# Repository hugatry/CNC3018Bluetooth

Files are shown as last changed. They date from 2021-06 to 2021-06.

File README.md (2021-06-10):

# CNC3018Bluetooth
 HM-10 based bluetooth module for CNC 3018 (Pro). Works with Woodpecker 3.4 and other compatible CNC controller boards.
 
 [Video introducing/testing this project](https://youtu.be/gbWO2Mq1XHM)

## HM-10 configuration
 This add-on module is ment to be used with HM-10 based USB dongle.
 Starting from HM-10 default configuration, CNC add-on module works as is, but USB-dongle needs to be set as Central/Master with "AT+ROLE1".
 
 It's recommended to use firmware version V700 or newer, which has correct baud rate and possibly other configurations as default. Hm-10 modules with older firmware may or may not work.
 
 ## Changes after the video, before the initial commit:
 * Ground pour removed behind the antenna
 * HM-10 ground pads are actually connected to the circuit :)

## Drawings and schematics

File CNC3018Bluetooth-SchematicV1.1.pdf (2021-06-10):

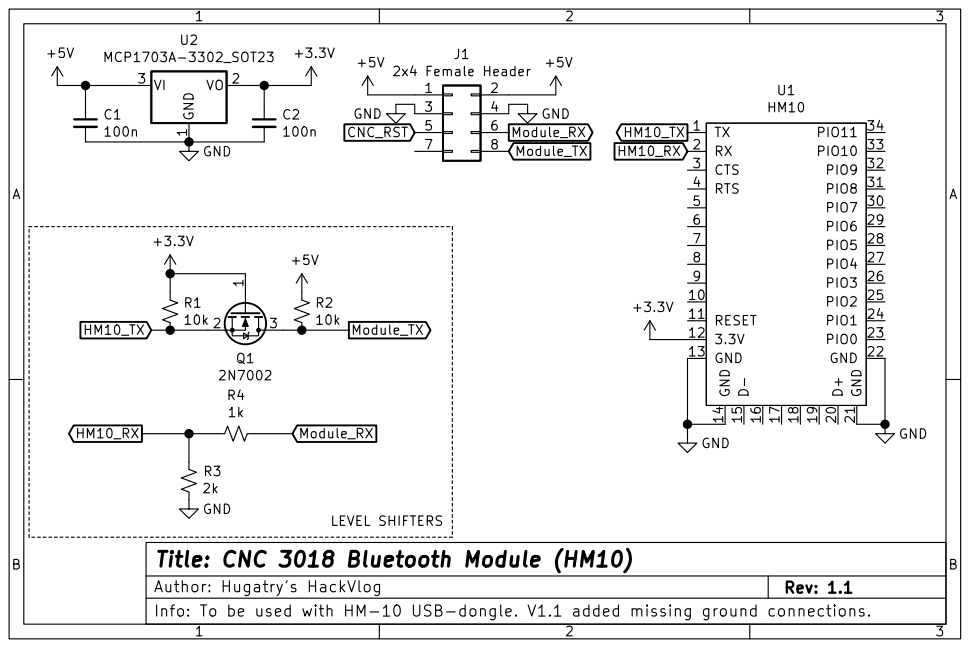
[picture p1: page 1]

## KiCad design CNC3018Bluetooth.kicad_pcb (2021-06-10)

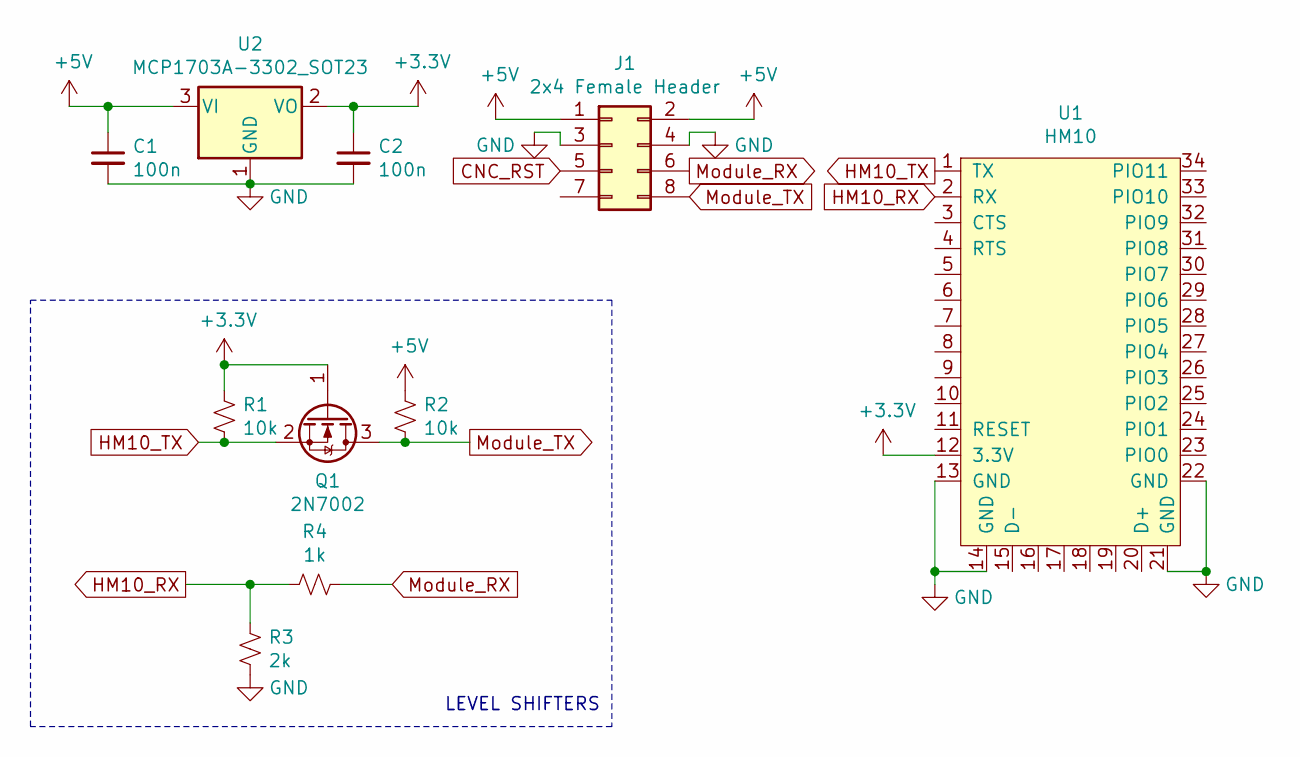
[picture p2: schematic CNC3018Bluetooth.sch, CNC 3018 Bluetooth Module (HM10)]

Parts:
C1, C2: 100n; C_0603_1608Metric
J1: 2x4 Female Header; PinSocket_2x04_P2.54mm_Vertical
Q1: 2N7002; SOT-23
R1, R2: 10k; R_0603_1608Metric
R3: 2k; R_0603_1608Metric
R4: 1k; R_0603_1608Metric
U1: HM10
U2: MCP1703A-3302_SOT23; SOT-23

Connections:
+3V3: C2.1, Q1.1 (G), R1.1, U1.12 (3.3V), U2.2 (VO)
+5V: C1.1, J1.1, J1.2, R2.1, U2.3 (VI)
CNC_RST: J1.5
GND: C1.2, C2.2, J1.3, J1.4, R3.1, U1.13 (GND), U1.14 (GND), U1.21 (GND), U1.22 (GND), U2.1 (GND)
HM10_RX: R3.2, R4.2, U1.2 (RX)
HM10_TX: Q1.2 (S), R1.2, U1.1 (TX)
Module_RX: J1.6, R4.1
Module_TX: J1.8, Q1.3 (D), R2.2

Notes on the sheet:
LEVEL SHIFTERS

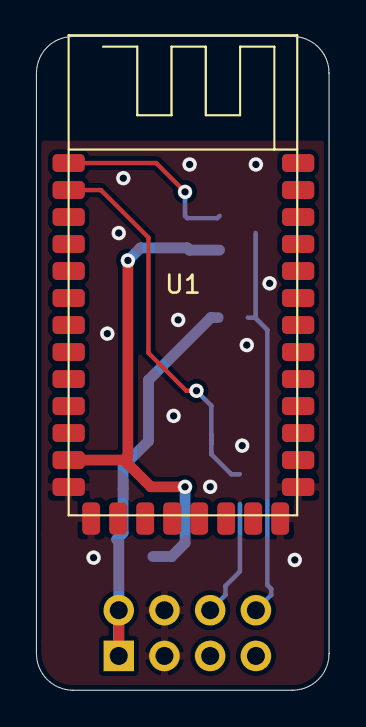
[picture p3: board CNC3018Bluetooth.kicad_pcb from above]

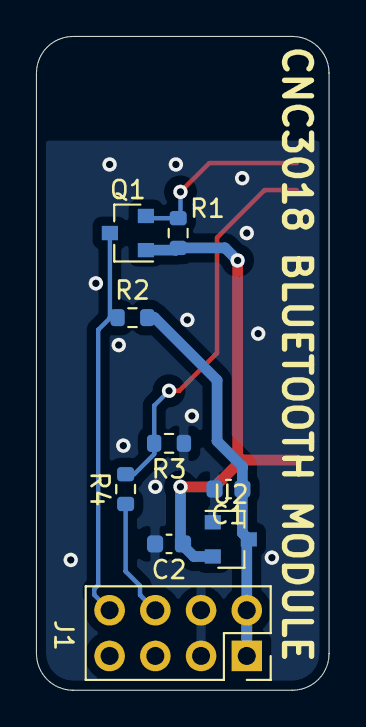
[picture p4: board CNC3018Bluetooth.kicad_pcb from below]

Board: 2 copper layers, 16.3 x 36.3 mm, 10 parts (9 on the bottom side), 7 nets.
